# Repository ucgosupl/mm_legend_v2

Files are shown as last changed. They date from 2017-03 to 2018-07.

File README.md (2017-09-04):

# Legend v2 - the micromouse robot

master: 

dev: 

The purpose of micromouse robot is to find path in the labirynth. To accomplish this task, robot should control its motors, detect walls using distance sensors and run pathfinding alhorithms.

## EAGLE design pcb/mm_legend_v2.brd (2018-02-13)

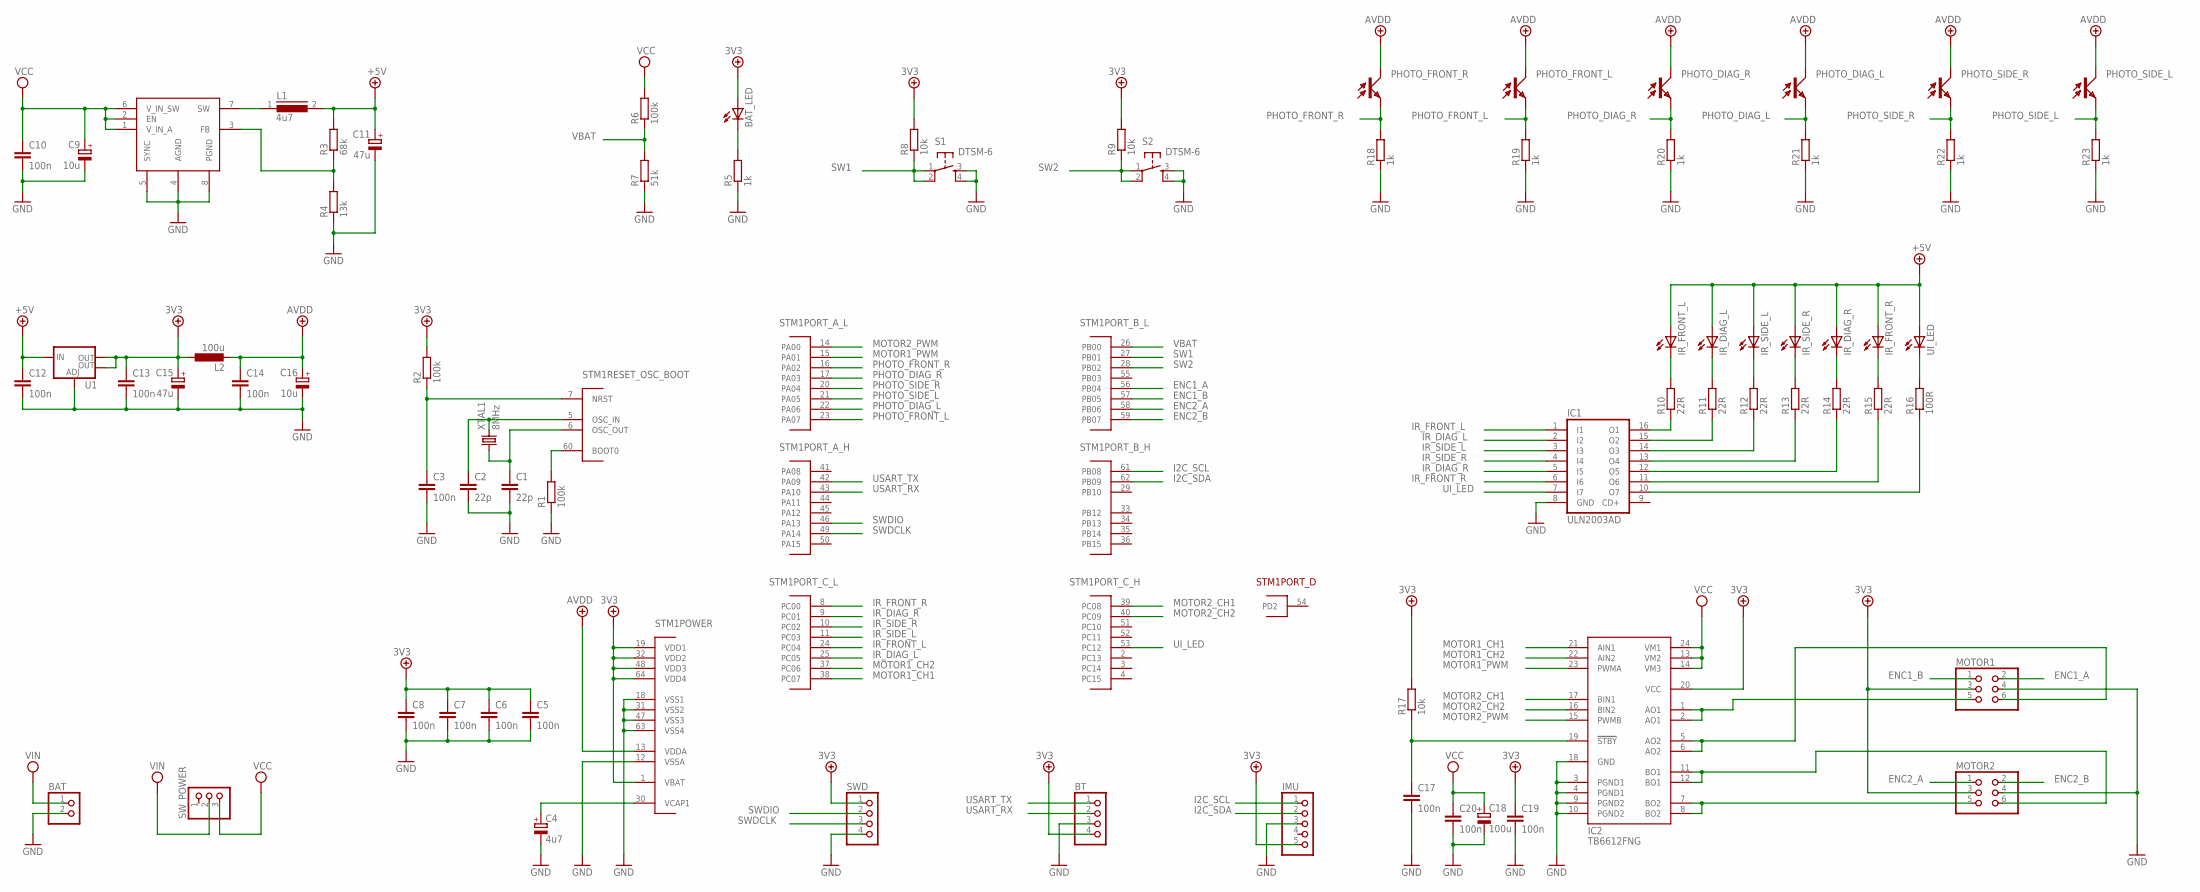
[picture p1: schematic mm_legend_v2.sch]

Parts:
BAT: PINHD-1X2; 1X02
BAT_LED: LEDCHIP-LED0805; CHIP-LED0805
BT: PINHD-1X4; 1X04
C1, C2: 22p; C0805K
C3, C5, C6, C7, C8, C10, C12, C13, C14, C17, C19, C20: 100n; C0805K
C4: 4u7; A/3216-18R
C9, C16: 10u; A/3216-18R
C11, C15: 47u; B/3528-21W
C18: 100u; C/6032-28R
IC1: ULN2003AD; SO16
IC2: TB6612FNG; SSOP24
IMU: PINHD-1X5; 1X05
IR_DIAG_L: LED5MM
IR_DIAG_R: LED5MM
IR_FRONT_L: LED5MM
IR_FRONT_R: LED5MM
IR_SIDE_L: LED5MM
IR_SIDE_R: LED5MM
L1: 4u7; DR74
L2: 100u; L1812
MOTOR1, MOTOR2: PINHD-2X3; 2X03
PHOTO_DIAG_L: PHOTO_TRANSISTOR_5MM; 5MM
PHOTO_DIAG_R: PHOTO_TRANSISTOR_5MM; 5MM
PHOTO_FRONT_L: PHOTO_TRANSISTOR_5MM; 5MM
PHOTO_FRONT_R: PHOTO_TRANSISTOR_5MM; 5MM
PHOTO_SIDE_L: PHOTO_TRANSISTOR_5MM; 5MM
PHOTO_SIDE_R: PHOTO_TRANSISTOR_5MM; 5MM
R1, R2, R6: 100k; R0805W
R3: 68k; R0805W
R4: 13k; R0805W
R5, R18, R19, R20, R21, R22, R23: 1k; R0805W
R7: 51k; R0805W
R8, R9, R17: 10k; R0805W
R10, R11, R12, R13, R14, R15: 22R; R0805W
R16: 100R; R0805W
S1, S2: DTSM-6
STM1: STM32F401RB; LQFP64
SWD: PINHD-1X4; 1X04
SW_POWER: PINHD-1X3; 1X03
U1: V_REG_LM1117SOT223; SOT223
U$2: ST1S10PHR; SO8
UI_LED: LEDCHIP-LED0805; CHIP-LED0805
XTAL1: 8MHz; SMD_50X32

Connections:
3V3: BAT_LED.A, BT.4, C5.1, C6.1, C7.1, C8.1, C13.1, C15.+, C19.1, IC2.20 (VCC), IMU.5, L2.1, MOTOR1.3, MOTOR2.3, R2.2, R8.2, R9.2, R17.2, STM1.1 (VBAT), STM1.19 (VDD1), STM1.32 (VDD2), STM1.48 (VDD3), STM1.64 (VDD4), SWD.1, U1.2 (OUT), U1.4 (OUT)
+5V: C11.+, C12.1, IR_DIAG_L.A, IR_DIAG_R.A, IR_FRONT_L.A, IR_FRONT_R.A, IR_SIDE_L.A, IR_SIDE_R.A, L1.2, R3.2, U1.3 (IN), UI_LED.A
AVDD: C14.1, C16.+, L2.2, PHOTO_DIAG_L.C, PHOTO_DIAG_R.C, PHOTO_FRONT_L.C, PHOTO_FRONT_R.C, PHOTO_SIDE_L.C, PHOTO_SIDE_R.C, STM1.13 (VDDA)
ENC1_A: MOTOR1.2, STM1.56 (PB04)
ENC1_B: MOTOR1.1, STM1.57 (PB05)
ENC2_A: MOTOR2.1, STM1.58 (PB06)
ENC2_B: MOTOR2.2, STM1.59 (PB07)
GND: BAT.2, BT.3, C1.2, C2.2, C3.2, C4.-, C5.2, C6.2, C7.2, C8.2, C9.-, C10.2, C11.-, C12.2, C13.2, C14.2, C15.-, C16.-, C17.2, C18.-, C19.2, C20.2, IC1.8 (GND), IC2.3 (PGND1), IC2.4 (PGND1), IC2.9 (PGND2), IC2.10 (PGND2), IC2.18 (GND), IMU.3, MOTOR1.4, MOTOR2.4, R1.1, R4.1, R5.1, R7.1, R18.1, R19.1, R20.1, R21.1, R22.1, R23.1, S1.3, S1.4, S2.3, S2.4, STM1.12 (VSSA), STM1.18 (VSS1), STM1.31 (VSS2), STM1.47 (VSS3), STM1.63 (VSS4), SWD.4, U1.1 (ADJ), U$2.4 (AGND), U$2.5 (SYNC), U$2.8 (PGND)
I2C_SCL: IMU.1, STM1.61 (PB08)
I2C_SDA: IMU.2, STM1.62 (PB09)
IR_DIAG_L: IC1.2 (I2), STM1.25 (PC05)
IR_DIAG_R: IC1.5 (I5), STM1.9 (PC01)
IR_FRONT_L: IC1.1 (I1), STM1.24 (PC04)
IR_FRONT_R: IC1.6 (I6), STM1.8 (PC00)
IR_SIDE_L: IC1.3 (I3), STM1.11 (PC03)
IR_SIDE_R: IC1.4 (I4), STM1.10 (PC02)
MOTOR1_CH1: IC2.21 (AIN1), STM1.38 (PC07)
MOTOR1_CH2: IC2.22 (AIN2), STM1.37 (PC06)
MOTOR1_PWM: IC2.23 (PWMA), STM1.15 (PA01)
MOTOR2_CH1: IC2.17 (BIN1), STM1.39 (PC08)
MOTOR2_CH2: IC2.16 (BIN2), STM1.40 (PC09)
MOTOR2_PWM: IC2.15 (PWMB), STM1.14 (PA00)
unnamed: R1.2, STM1.60 (BOOT0)
unnamed: C3.1, R2.1, STM1.7 (NRST)
unnamed: C1.1, STM1.6 (OSC_OUT), XTAL1.1
unnamed: C2.1, STM1.5 (OSC_IN), XTAL1.2
unnamed: BAT_LED.C, R5.2
unnamed: C17.1, IC2.19 (!STBY), R17.1
unnamed: R16.2, UI_LED.C
unnamed: IR_FRONT_L.K (C), R10.2
unnamed: C4.+, STM1.30 (VCAP1)
unnamed: IR_DIAG_L.K (C), R11.2
unnamed: IR_SIDE_L.K (C), R12.2
unnamed: IR_SIDE_R.K (C), R13.2
unnamed: IR_DIAG_R.K (C), R14.2
unnamed: IR_FRONT_R.K (C), R15.2
unnamed: IC1.16 (O1), R10.1
unnamed: IC1.15 (O2), R11.1
unnamed: IC1.14 (O3), R12.1
unnamed: IC1.13 (O4), R13.1
unnamed: IC1.12 (O5), R14.1
unnamed: IC1.11 (O6), R15.1
unnamed: IC1.10 (O7), R16.1
unnamed: L1.1, U$2.7 (SW)
unnamed: IC2.1 (AO1), IC2.2 (AO1), MOTOR1.5
unnamed: IC2.5 (AO2), IC2.6 (AO2), MOTOR1.6
unnamed: R3.1, R4.2, U$2.3 (FB)
unnamed: IC2.11 (BO1), IC2.12 (BO1), MOTOR2.6
unnamed: IC2.7 (BO2), IC2.8 (BO2), MOTOR2.5
PHOTO_DIAG_L: PHOTO_DIAG_L.E, R21.2, STM1.22 (PA06)
PHOTO_DIAG_R: PHOTO_DIAG_R.E, R20.2, STM1.17 (PA03)
PHOTO_FRONT_L: PHOTO_FRONT_L.E, R19.2, STM1.23 (PA07)
PHOTO_FRONT_R: PHOTO_FRONT_R.E, R18.2, STM1.16 (PA02)
PHOTO_SIDE_L: PHOTO_SIDE_L.E, R23.2, STM1.21 (PA05)
PHOTO_SIDE_R: PHOTO_SIDE_R.E, R22.2, STM1.20 (PA04)
SW1: R8.1, S1.1, S1.2, STM1.27 (PB01)
SW2: R9.1, S2.1, S2.2, STM1.28 (PB02)
SWDCLK: STM1.49 (PA14), SWD.3
SWDIO: STM1.46 (PA13), SWD.2
UI_LED: IC1.7 (I7), STM1.53 (PC12)
USART_RX: BT.2, STM1.43 (PA10)
USART_TX: BT.1, STM1.42 (PA09)
VBAT: R6.1, R7.2, STM1.26 (PB00)
VCC: C9.+, C10.1, C18.+, C20.1, IC2.13 (VM2), IC2.14 (VM3), IC2.24 (VM1), R6.2, SW_POWER.3, U$2.1 (V_IN_A), U$2.2 (EN), U$2.6 (V_IN_SW)
VEE: BAT.1, SW_POWER.2

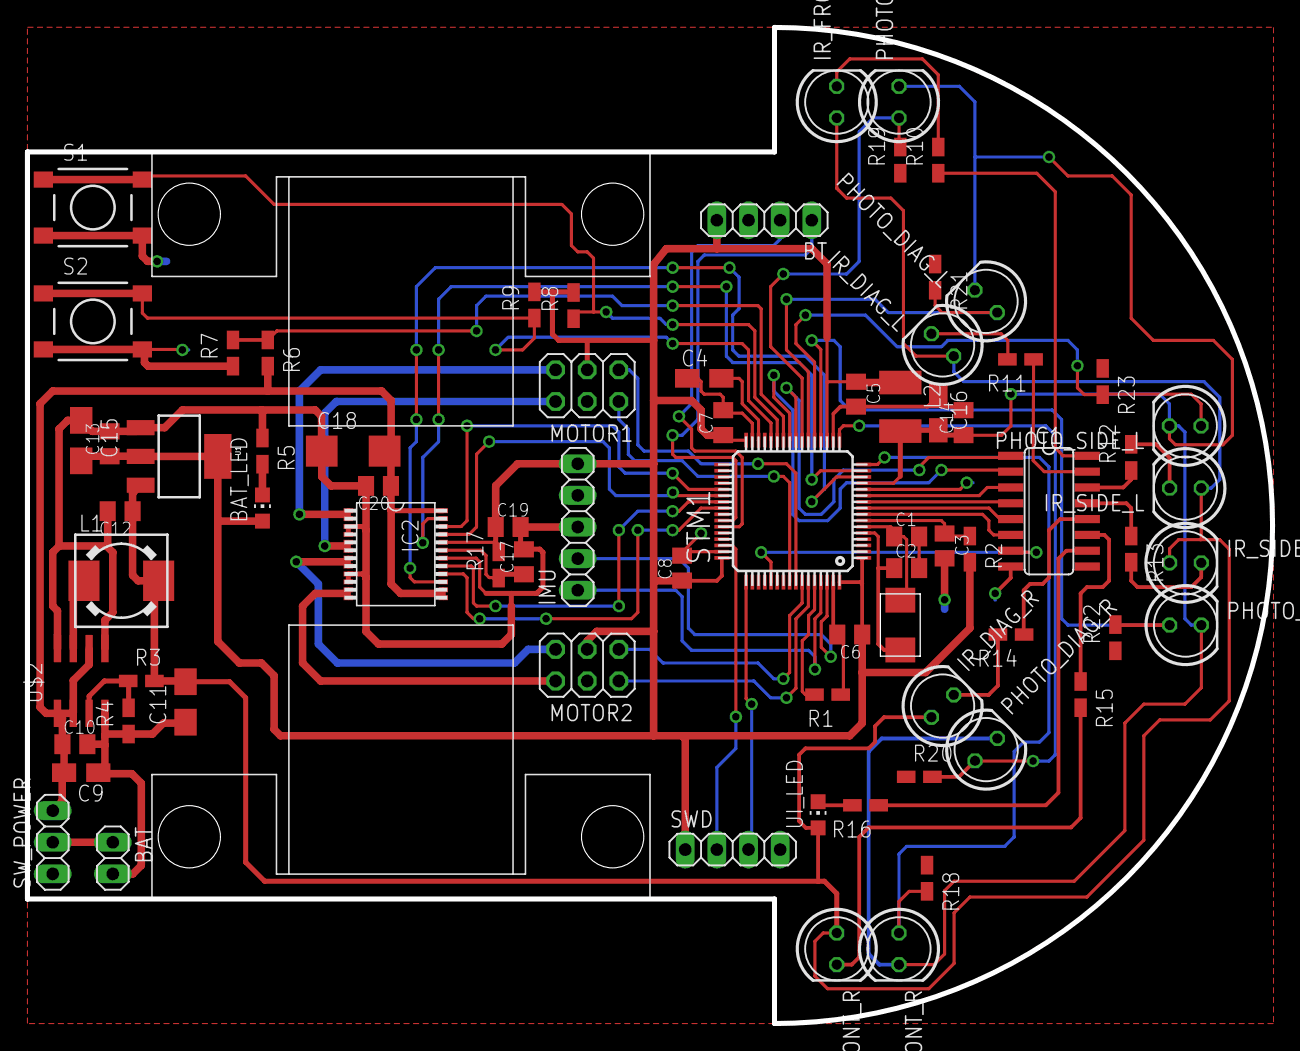
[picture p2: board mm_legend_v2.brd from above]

Board: 2 copper layers, 100.0 x 80.0 mm, 76 parts (0 on the bottom side), 65 nets.

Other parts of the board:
U$1, U$3: MOTOR_HOLDER

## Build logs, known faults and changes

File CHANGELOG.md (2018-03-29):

Changelog
============
All notable changes to this project will be documented in this file.

The format is based on [Keep a Changelog](http://keepachangelog.com/en/1.0.0/)
and this project adheres to [Semantic Versioning](http://semver.org/spec/v2.0.0.html).

## [Unreleased]
------------------------

### Added

### Changed

### Fixed

### Deprecated

### Removed

## [0.5.0] - 2018-03-30
------------------------

### Added
- map_update: present/absent wall detection.
- map_validate: present/absent walls are added only after their detection count reaches threshold.
- wall_detection: wall sensor position calculation based on offset from robot position.
- wall_detection: wall detection position calculation based on sensor position and measured distance.

### Changed
- map: change wall orientation so x and y indices grow with coordinates.
- mazetool: update print functions to show maze in proper orientation.
- wall_sensor: change module name from wall to wall_sensor.

### Fixed

### Deprecated

### Removed

## [0.5.0] - 2018-03-24
------------------------

### Added
- adc: add adc implementation.
- led: add led driver implementation.
- map: add module storing labirynth map.
- pcb: new PCB design.
- project: add incremental compilation to makefiles.
- scripts: add scripts for generating sensor lookup table from measurements.
- solver: add implementation of maze solver.
- vbat: add battery saving procedure.
- wall: add wall sensor task.
- wall: add conversion routine separate for every sensor.

### Changed
- pcb: move status led to the front.

### Fixed
- pcb: change wall sensor placement - Fixes issue #7.
- pcb: reroute paths to h-bridge around imu sensor - Fixes issue #6.
- pcb: fix motor connector wiring - Fixes issue #1.

### Deprecated

### Removed

## [0.4.0] - 2017-12-23
------------------------

### Added
- external: add matrix calculations library.
- position: implement position estimation based on EKF.
- position: implement gyro drift reduction.

### Changed

### Fixed
- imu: add timeout in startup procedure to eliminate junk readings.

### Deprecated

### Removed

## [0.3.0] - 2017-11-18
------------------------

### Added
- encoder: implement encoders driver.
- i2c: add i2c master driver.
- imu: add IMU task reading data from sensor.
- logger: implement logger task and integrate it with system printf.
- motor: implement PID controller for forward velocity.
- motor: implement PID controller for angular velocity.
- pcb: fix motor connectors and BT connector.
- uart: implement Tx functionality.

### Changed

### Fixed
- ci: Travis failing after gcc update - use fixed gcc version and precompiled binary.

### Deprecated

### Removed

## [0.2.0] - 2017-07-02
------------------------

### Added
- console: added ability to control motors manually using console.
- console: implement uart console task.
- hbridge: TB6612 H-Bridge driver implementation.
- src: added skeleton interfaces for code components.
- uart: implement Rx functionality.

### Changed

### Fixed
- src: fixed wrong bus frequency definitions.

### Deprecated

### Removed

## [0.1.1] - 2017-04-22
------------------------

### Added

### Changed

### Fixed
- ci: remove Travis-CI dependency on fixed gcc version.

### Deprecated

### Removed

## 0.1.0 - 2017-04-22
------------------------

### Added
- ci: initial Travis-CI configuration.
- pcb: designed electric circuit.
- pcb: designed PCB.
- src: initial project setup.
- unit_test: configured CppUTest.

### Changed

### Fixed

### Deprecated

### Removed

[Unreleased]: https://github.com/ucgosupl/mm_legend_v2/compare/v0.5.0...dev
[0.1.1]: https://github.com/ucgosupl/mm_legend_v2/compare/v0.1.0...v0.1.1
[0.2.0]: https://github.com/ucgosupl/mm_legend_v2/compare/v0.1.1...0.2.0
[0.3.0]: https://github.com/ucgosupl/mm_legend_v2/compare/0.2.0...v0.3.0
[0.4.0]: https://github.com/ucgosupl/mm_legend_v2/compare/0.3.0...v0.4.0
[0.5.0]: https://github.com/ucgosupl/mm_legend_v2/compare/0.4.0...v0.5.0
[0.6.0]: https://github.com/ucgosupl/mm_legend_v2/compare/0.5.0...v0.6.0

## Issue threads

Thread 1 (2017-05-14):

PCB error - wrong pinout on motor connectors

ucgosupl, 2017-05-14:
According to documentation, Faulhaber 1717T006IE16 connector have following pinout:
6 4 2
5 3 1

where:
1 - motor -
2 - motor +
3 - GND
4 - VCC
5 - Encoder B
6 - Encoder A

On the board connector is:
5 3 1
6 4 2
Pins 5-6 and 1-2 can be inverted but inverting 3-4 causes providing negative voltage to the board.

ucgosupl, 2017-10-22:
Left motor connector still with wrong pinout

Closed 2018-02-14.

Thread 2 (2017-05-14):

Design and 3D print gear mounted to motor shaft using screw

ucgosupl, 2017-05-14:
Principle of operation like in: https://www.ctmeca.com/vitnw/technicalFilesCtmeca.php?item=F first method.
Need to check if it is possible to 3D print gear to be used with M1.6 screw.

ucgosupl, 2017-09-24:
Screws are glued and it works fine.

Closed 2017-09-24.

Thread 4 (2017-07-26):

Motor identifiaction

ucgosupl, 2017-07-26:
Gather motor-encoder characteristics for various motor power settings.

ucgosupl, 2017-07-26:
Gathered data in commit: 9c18ef3
Now need to determine transfer function based on these data. There will be separate TF for left and right motor as they behave diffferently due to inaccuracy of mechanical parts.

ucgosupl, 2017-08-08:
Gathered transfer functions.
For left motor: 1.682 / (0.2742 s + 1)
For right motor: 1.59 / (0.2222 s + 1)

PID settings for these models:
P = 2.61, I = 11.58, D = 0

The same PID will be used for both motors

ucgosupl, 2017-09-04:
Made adjustments to model. New model is:
1.4 / (0.215 s + 1)

New PID values for linear velocity are:
P = 6.6869
I  = 0.0
D = 0.03639

ucgosupl, 2017-09-24:
Tuned pid for linear velocity, but glued wheels have other characteristics so all process should be repeated.

Closed 2017-09-24.

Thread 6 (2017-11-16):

PCB - motor direction paths

ucgosupl, 2017-11-16:
Signals Motor 1/2 CH1/2 should be routed around imu connector, not between bads. Thin routes are easy to damage.

Closed 2018-02-14.

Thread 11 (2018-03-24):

[unit_test] Change unit test framework to Unity + mocklib

ucgosupl, 2018-03-24:
CppUTest mocking features are not enough for my use and are hard to configure.
Eclipse doesn't support cpp that well or I have problems with proper configuration.
Using mocklib will be opportunity to improve my mocklib project.

ucgosupl, 2018-04-08:
Decided to give CppUTest one more try. Won't fix for now.

Closed 2018-04-08.

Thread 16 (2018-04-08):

[search] add info about robot orientation to state machine

ucgosupl, 2018-04-08:
State machine needs info about current robot orientation to be able to choose correct next move.

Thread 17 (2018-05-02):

Add emergency stop when too close to wall

ucgosupl, 2018-05-02:
To avoid collision, navigation algorithm should be replaced by emergency stop to protect robot from damage. Along with stopping all motors, console message and led signal should be added so this state is easly recognized.

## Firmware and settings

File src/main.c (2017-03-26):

/*
 * File: main.c
 * Author: GAndaLF
 * Brief: Main file for main_program target.
 */

#include "platform_specific.h"

#include "FreeRTOSConfig.h"
#include "FreeRTOS.h"
#include "task.h"
#include "queue.h"
#include "timers.h"
#include "semphr.h"

#include "core_init/core_init.h"
#include "diag/diag.h"

void main(void)
{
    core_init();

    /* Place your initialisation code here. */
    diag_task_init();
    vTaskStartScheduler();

    while (1)
        ;
}

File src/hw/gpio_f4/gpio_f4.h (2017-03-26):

/*
 * File:    gpio_f4.h
 * Author:  GAndaLF
 * Brief:   GPIO configuration functions.
 */

#ifndef _GPIO_F4_H_
#define _GPIO_F4_H_

#ifdef __cplusplus
 extern "C" {
#endif /* __cplusplus */

/**
 * @defgroup hw_gpio
 * @{
 */

/** GPIO mode of operation - input. */
#define GPIO_MODE_INPUT       0
/** GPIO mode of operation - output. */
#define GPIO_MODE_OUTPUT      1
/** GPIO mode of operation - alternative function. */
#define GPIO_MODE_AF          2
/** GPIO mode of operation - analog input. */
#define GPIO_MODE_ANALOG      3

/** GPIO state change speed - low. */
#define GPIO_SPEED_LOW        0
/** GPIO state change speed - medium. */
#define GPIO_SPEED_MEDIUM     1
/** GPIO state change speed - fast. */
#define GPIO_SPEED_FAST       2
/** GPIO state change speed - high. */
#define GPIO_SPEED_HIGH       3

/** GPIO input pull up/down setting - none. */
#define GPIO_PUPD_NONE        0
/** GPIO input pull up/down setting - pull up. */
#define GPIO_PUPD_PU          1
/** GPIO input pull up/down setting - pull down. */
#define GPIO_PUPD_PD          2

/** GPIO alternative function - JTAG. */
#define GPIO_AF_JTAG          0
/** GPIO alternative function - Microcontroller Clock Output. */
#define GPIO_AF_MCO           0
/** GPIO alternative function - RTC. */
#define GPIO_AF_RTC           0
/** GPIO alternative function - TRACE. */
#define GPIO_AF_TRACE         0
/** GPIO alternative function - Timer 1. */
#define GPIO_AF_TIM1          1
/** GPIO alternative function - Timer 2. */
#define GPIO_AF_TIM2          1
/** GPIO alternative function - Timer 3. */
#define GPIO_AF_TIM3          2
/** GPIO alternative function - Timer 4. */
#define GPIO_AF_TIM4          2
/** GPIO alternative function - Timer 5. */
#define GPIO_AF_TIM5          2
/** GPIO alternative function - Timer 8. */
#define GPIO_AF_TIM8          3
/** GPIO alternative function - Timer 9. */
#define GPIO_AF_TIM9          3
/** GPIO alternative function - Timer 10. */
#define GPIO_AF_TIM10         3
/** GPIO alternative function - Timer 11. */
#define GPIO_AF_TIM11         3
/** GPIO alternative function - I2C 1. */
#define GPIO_AF_I2C1          4
/** GPIO alternative function - I2C 2. */
#define GPIO_AF_I2C2          4
/** GPIO alternative function - I2C 3. */
#define GPIO_AF_I2C3          4
/** GPIO alternative function - SPI 1. */
#define GPIO_AF_SPI1          5
/** GPIO alternative function - SPI 2. */
#define GPIO_AF_SPI2          5
/** GPIO alternative function - I2S 2. */
#define GPIO_AF_I2S2          5
/** GPIO alternative function - I2S 2 EXT. */
#define GPIO_AF_I2S2EXT       5
/** GPIO alternative function - SPI 3. */
#define GPIO_AF_SPI3          6
/** GPIO alternative function - I2S EXT. */
#define GPIO_AF_I2SEXT        6
/** GPIO alternative function - I2S 3. */
#define GPIO_AF_I2S3          6
/** GPIO alternative function - USART 1. */
#define GPIO_AF_USART1        7
/** GPIO alternative function - USART 2. */
#define GPIO_AF_USART2        7
/** GPIO alternative function - USART 3. */
#define GPIO_AF_USART3        7
/** GPIO alternative function - I2S 3 EXT. */
#define GPIO_AF_I2S3EXT       7
/** GPIO alternative function - UART 4. */
#define GPIO_AF_UART4         8
/** GPIO alternative function - UART 5. */
#define GPIO_AF_UART5         8
/** GPIO alternative function - USART6. */
#define GPIO_AF_USART6        8
/** GPIO alternative function - CAN 1. */
#define GPIO_AF_CAN1          9
/** GPIO alternative function - CAN 2. */
#define GPIO_AF_CAN2          9
/** GPIO alternative function - Timer 12. */
#define GPIO_AF_TIM12         9
/** GPIO alternative function - Timer 13. */
#define GPIO_AF_TIM13         9
/** GPIO alternative function - Timer 14. */
#define GPIO_AF_TIM14         9
/** GPIO alternative function - USB On-The-Go Full Speed 1. */
#define GPIO_AF_OTGFS1        10
/** GPIO alternative function - USB On-The-Go High Speed. */
#define GPIO_AF_OTGHS         10
/** GPIO alternative function - Ethernet. */
#define GPIO_AF_ETH           11
/** GPIO alternative function - FSMC. */
#define GPIO_AF_FSMC          12
/** GPIO alternative function - SDIO. */
#define GPIO_AF_SDIO          12
/** GPIO alternative function - USB On-The-Go Full Speed 2. */
#define GPIO_AF_OTGFS2        12
/** GPIO alternative function - DCMI. */
#define GPIO_AF_DCMI          13
/** GPIO alternative function - Alternative function 14. */
#define GPIO_AF_AF14          14
/** GPIO alternative function - Eventout. */
#define GPIO_AF_EVENTOUT      15

/**
 * @brief Function sets GPIO pin mode.
 *
 * @param gpio                         Port to set.
 * @param pin                          Pin to set.
 * @param conf                         Mode to set.
 */
void gpio_mode_config(GPIO_TypeDef * gpio, int32_t pin, int32_t conf);

/**
 * @brief Function sets GPIO pin in push-pull mode.
 *
 * @param gpio                         Port to set.
 * @param pin                          Pin to set.
 */
#define gpio_otype_pp_set(gpio, pin)   gpio->OTYPER &= ~(1<<pin);
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

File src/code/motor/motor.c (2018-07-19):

/*
 * file:	motor.c
 * author:	GAndaLF
 * brief:   Motor control task.
 */

#include "platform_specific.h"
#include <string.h>
#include <stdlib.h>
#include <math.h>

#include "encoder/encoder.h"
#include "hbridge/hbridge.h"
#include "pid/pid.h"

#include "motor.h"

/** Maximum allowed motor power. */
#define MOTOR_POWER_MAX     1000

/** Minimum allowed motor power. */
#define MOTOR_POWER_MIN     0

/** Number of cogs in motor gear. */
#define GEAR_MOTOR              10.0f
/** Number of cogs in wheel gear. */
#define GEAR_WHEEL              40.0f
/** Number of encoder ticks per full motor cycle - 16 ticks per cycle, rising and falling edge, A and B. */
#define TICKS_PER_MOTOR_CYCLE   64.0f
/** Circumference of the wheel. */
#define WHEEL_CIRC_MM           69.0f

/** Convert encoder ticks to mm. */
#define TICKS_TO_MM(ticks)      \
    (((ticks) * GEAR_MOTOR * WHEEL_CIRC_MM) / (GEAR_WHEEL * TICKS_PER_MOTOR_CYCLE))

/** Convert mm to encoder ticks. */
#define MM_TO_TICKS(mm)         \
    (((mm) * GEAR_WHEEL * TICKS_PER_MOTOR_CYCLE) / (GEAR_MOTOR * WHEEL_CIRC_MM))

#define SAMPLING_TIME_S 0.010f

/** Forward velocity controller PID proportional gain. */
#define FORWARD_PID_P   2.0f
/** Forward velocity controller PID integral gain. */
#define FORWARD_PID_I   (1.0f * SAMPLING_TIME_S)
/** Forward velocity controller PID derivative gain. */
#define FORWARD_PID_D   (0.0f / SAMPLING_TIME_S)

/** Angular velocity controller PID proportional gain. */
#define ANGULAR_PID_P   1.0f
/** Angular velocity controller PID integral gain. */
#define ANGULAR_PID_I   (1.0f * SAMPLING_TIME_S)
/** Angular velocity controller PID derivative gain. */
#define ANGULAR_PID_D   (0.0f / SAMPLING_TIME_S)

#define MOTOR_ANGULAR_OFFSET    0

#define ROBOT_WIDTH_MM  80.0f

struct motor_params
{
    float vlinear;
    float vangular;

    int32_t vleft_read;
    int32_t vright_read;
};

static struct motor_params motor_params;
static struct pid_params forward_pid;
static struct pid_params angular_pid;

static void motor_task(void *params);
static int32_t motor_power_limits(float u);

void motor_task_init(void)
{
    memset(&motor_params, 0, sizeof(struct motor_params));

    pid_init(&forward_pid, FORWARD_PID_P, FORWARD_PID_I, FORWARD_PID_D);
    pid_init(&angular_pid, ANGULAR_PID_P, ANGULAR_PID_I, ANGULAR_PID_D);

    encoder_init();
    hbridge_init();

    rtos_task_create(motor_task, "motor", MOTOR_STACKSIZE, MOTOR_PRIORITY);
}

float motor_vleft_get(void)
{
    return TICKS_TO_MM(motor_params.vleft_read);
}

float motor_vright_get(void)
{
    return TICKS_TO_MM(motor_params.vright_read);
}

void motor_vlinear_set(float val)
{
    motor_params.vlinear = MM_TO_TICKS(2.0f * val * SAMPLING_TIME_S);
}

void motor_vangular_set(float val)
{
    motor_params.vangular = MM_TO_TICKS(val * 2.0f * M_PI *
            ROBOT_WIDTH_MM * SAMPLING_TIME_S / 360.0f);
}

void motor_all_off(void)
{
    hbridge_left_speed_set(0);
    hbridge_right_speed_set(0);
}

void motor_pid_linear_reset(void)
{
    pid_reset(&forward_pid);
}

void motor_pid_angular_reset(void)
{
    pid_reset(&angular_pid);
}

static void motor_task(void *params)
{
    (void) params;

    float forward;
    float angle;
    float u_forward = 0;
    float u_angular = 0;
    float u_left = 0;
    float u_right = 0;
    tick_t last;

    while (1)
    {
        last = rtos_tick_count_get();

        motor_params.vleft_read = encoder_left_read();
        motor_params.vright_read = encoder_right_read();

        forward = motor_params.vright_read + motor_params.vleft_read;
        angle = motor_params.vright_read - motor_params.vleft_read;

        /* Forward controller */
        u_forward = pid_iter(&forward_pid, motor_params.vlinear, forward);

        /* Angular controller */
        u_angular = pid_iter(&angular_pid, motor_params.vangular, angle);

        /* Fusion of two controllers */
        u_left = u_forward - u_angular + MOTOR_ANGULAR_OFFSET;
        u_right = u_forward + u_angular - MOTOR_ANGULAR_OFFSET;

        /* Limits */
        u_left = motor_power_limits(u_left);
        u_right = motor_power_limits(u_right);

        hbridge_left_speed_set(u_left);
        hbridge_right_speed_set(u_right);

        rtos_delay_until(&last, 10);
    }
}

static int32_t motor_power_limits(float u)
{
    int32_t retval;
    int32_t u_int;

    u_int = (int32_t)u;

    /* Maximum motor power value conditions - bigger values are not handled. */
    if (MOTOR_POWER_MAX < u_int)
    {
        retval = MOTOR_POWER_MAX;
    }
    else if (-MOTOR_POWER_MAX > u_int)
    {
        retval = -MOTOR_POWER_MAX;
    }
    /* Minimum nonzero value condition - lower values might damage motor. */
    else if (MOTOR_POWER_MIN > abs(u_int))
    {
        retval = 0;
    }
    else
    {
        /* Input value correct, don't need to do anything. */
        retval = u_int;
    }

    return retval;
}

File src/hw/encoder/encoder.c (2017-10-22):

/*
 * file:	encoder.c
 * author:	GAndaLF
 * brief:   Motor encoders driver.
 */

#include "platform_specific.h"

#include "gpio_f4/gpio_f4.h"

#include "encoder.h"

/** Encoder 1 channel A pin number - PB04 */
#define ENC_1A_PIN                  4
/** Encoder 1 channel B pin number - PB05 */
#define ENC_1B_PIN                  5
/** Encoder 2 channel A pin number - PB06 */
#define ENC_2A_PIN                  6
/** Encoder 2 channel B pin number - PB07 */
#define ENC_2B_PIN                  7

/**
 * Encoder mode 1 setting in SMS field of TIM->SMCR register.
 *
 * Count up-down only on channel A edge.
 */
#define TIM_SMS_MODE_ENC1           1
/**
 * Encoder mode 2 setting in SMS field of TIM->SMCR register.
 *
 * Count up-down only on channel B edge.
 */
#define TIM_SMS_MODE_ENC2           2
/**
 * Encoder mode 3 setting in SMS field of TIM->SMCR register.
 *
 * Count up-down on edge on either A or B channel.
 */
#define TIM_SMS_MODE_ENC3           3

/** Set Capture/Compare channel to output mode. */
#define TIM_CCxS_MODE_OUT           0
/** Set Capture/Compare channel to input mode mapped on TI1. */
#define TIM_CCxS_MODE_IN_T1         1
/** Set Capture/Compare channel to input mode mapped on TI2. */
#define TIM_CCxS_MODE_IN_T2         2
/** Set Capture/Compare channel to input mode mapped on TRC. */
#define TIM_CCxS_MODE_IN_TRC        3

/** Bit offset of SMS field in SMCR register. */
#define TIM_SMCR_SMS_BIT            0

/** Bit offset of CC1S field in CCMR1 register. */
#define TIM_CCMR1_CC1S_BIT          0
/** Bit offset of CC2S field in CCMR1 register. */
#define TIM_CCMR1_CC2S_BIT          8

/**
 * Initialize GPIOs for encoder inputs.
 */
static void gpio_init(void);

/**
 * Initialize timers for encoder inputs.
 */
static void timer_init(void);

void encoder_init(void)
{
    gpio_init();
    timer_init();
}

int32_t encoder_left_read(void)
{
    int16_t val;

    val = -TIM3->CNT;
    TIM3->CNT = 0;

    return (int32_t) val;
}

int32_t encoder_right_read(void)
{
    int16_t val;

    val = -TIM4->CNT;
    TIM4->CNT = 0;

    return (int32_t) val;
}

static void gpio_init(void)
{
    RCC->AHB1ENR |= RCC_AHB1ENR_GPIOBEN;

    gpio_mode_config(GPIOB, ENC_1A_PIN, GPIO_MODE_AF);
    gpio_mode_config(GPIOB, ENC_1B_PIN, GPIO_MODE_AF);
    gpio_mode_config(GPIOB, ENC_2A_PIN, GPIO_MODE_AF);
    gpio_mode_config(GPIOB, ENC_2B_PIN, GPIO_MODE_AF);

    gpio_af_config(GPIOB, ENC_1A_PIN, GPIO_AF_TIM3);
    gpio_af_config(GPIOB, ENC_1B_PIN, GPIO_AF_TIM3);
    gpio_af_config(GPIOB, ENC_2A_PIN, GPIO_AF_TIM4);
    gpio_af_config(GPIOB, ENC_2B_PIN, GPIO_AF_TIM4);
}

static void timer_init(void)
{
    RCC->APB1ENR |= RCC_APB1ENR_TIM3EN | RCC_APB1ENR_TIM4EN;

    /* Select encoder mode */
    TIM3->SMCR = (TIM_SMS_MODE_ENC3 << TIM_SMCR_SMS_BIT);
    TIM4->SMCR = (TIM_SMS_MODE_ENC3 << TIM_SMCR_SMS_BIT);

    /* Set CCR1 as T1, CCR2 as T2 */
    TIM3->CCMR1 = (TIM_CCxS_MODE_IN_T1 << TIM_CCMR1_CC1S_BIT) |
            (TIM_CCxS_MODE_IN_T1 << TIM_CCMR1_CC1S_BIT);
    TIM4->CCMR1 = (TIM_CCxS_MODE_IN_T1 << TIM_CCMR1_CC1S_BIT) |
            (TIM_CCxS_MODE_IN_T1 << TIM_CCMR1_CC1S_BIT);

    /* Configure auto reload, so 0xFFFF is after 0 when downcounting */
    TIM3->ARR = 0xFFFF;
    TIM4->ARR = 0xFFFF;

    /* Enable timers */
    TIM3->CR1 = TIM_CR1_CEN;
    TIM4->CR1 = TIM_CR1_CEN;
}

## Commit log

2017-03-05 pcb: added circuit diagram.
    [mm_legend_v2.sch]
2017-03-13 pcb: added library parts used for circuit and pcb.
2017-03-13 pcb: created pcb design.
    [mm_legend_v2.brd, mm_legend_v2.sch]
2017-03-18 pcb: minor changes in pcb and schematic.
    [mm_legend_v2.brd, mm_legend_v2.sch]
2017-03-18 pcb: redesigned pcb.
    [mm_legend_v2.brd]
2017-03-26 project: added cpputest unit test framework.
2017-05-03 led: added prototypes for led driver functions.
2017-05-03 adc: added prototypes for ADC driver functions.
2017-05-03 photo: added prototypes for phototransistor module functions.
2017-05-03 vbat: added prototypes for battery monitor functions.
2017-05-03 wall: added prototypes for wall detection module functions.
2017-05-03 hbridge: added prototypes for H-bridge module functions.
2017-05-03 encoder: added prototypes for encoder driver functions.
2017-05-03 pid: added prototypes for PID controller functions.
2017-05-03 motor: added prototypes for motor control module functions.
2017-05-03 i2c: added prototypes for I2C master driver.
2017-05-03 imu: added prototypes for IMU sensors module functions.
2017-05-09 usart: added prototypes for USART driver functions.
2017-05-09 logger: added prototypes for logger module functions.
2017-05-09 console: added prototypes for debug console functions.
2017-05-13 button: added prototypes for button driver functions.
2017-05-13 user_interface: added prototypes for user interface functions.
2017-05-13 hbridge: implemented H-bridge driver and hardware test.
2017-07-02 usart: add implementation of usart Tx.
    USART Tx is implemented using DMA.
    HW test target - logger - is created.
2017-07-02 logger: add logger implementation and connect it with system printf.
2017-07-26 hw_test: added motor_ident hw_test target.
2017-07-26 button: add button driver implementation.
2017-07-26 encoder: add encoder implementation
2017-07-26 data: gather motor identification data - issue #3
2017-07-28 data: create script for motor identification - refers to #4
2017-08-08 data: create matlab scripts for processing motor ident data - refers to #4.
2017-09-04 pid: add pid controller implementation.
2017-09-04 motor: add motor task implementation.
2017-09-04 hw_test: add motor linear regulation test.
2017-09-04 hw_test: add imu test template.
2017-09-06 imu: add i2c driver and imu task.
2017-09-15 hw_test/motor_linear: fixed header comments.
2017-09-24 pcb: update pcb and schematic.
    Changes:
    - Moved BT connector away from motor holder.
    - Changed pinout of motor connectors - fix issue #1.
    - Added thicker lines for motor + and - signals.
    [mm_legend_v2.brd, mm_legend_v2.sch]
2017-10-22 pcb: updated vbat resistors to real values.
    Until now resistor values were 20k and 100k. 20k resistor doesn't exist in the series.
    [mm_legend_v2.brd, mm_legend_v2.sch]
2017-10-22 motor: update forward and backward functions for new motor orientation.
2017-10-22 encoder: adjust encoder measurements to return positive values when moving forward.
2017-10-22 motor: calculate new PID settings for linear movement.
2017-10-23 imu: add initial delay to imu task to allow sensor to power up.
2017-10-23 hw_test/motor_ident: adapt for angular velocity.
2017-10-29 imu: change gyro and accelerometer sampling frequency.
    High sample frequency caused higher exposure to noise generated by mechanical vibration caused by motors.
    [imu.c]
2017-11-18 hbridge: increase motor power resolution from 100 to 1000.
2017-11-18 motor: change function return values to float in api functions.
2017-11-18 data: gather data for angular velocity controller.
2017-11-18 scripts: create script and simulink model for angular velocity controller tuning.
2017-11-18 motor: implement angular velocity controller.
    Also added tools for angular controller tests in hw test target motor_linear.
2017-11-18 scripts: update simulink model for angular velocity controller.
2017-12-07 motor: update angular controller to use correct orientation angle.
    [motor.c]
2017-12-13 position: fix bugs with position estimation.
    - Ticks per motor cycle now accounts for encoder rising/falling edge on both channels A and B
    - Angular velocity from gyroscope is counted backwards compared to orientation angle
    - Angular velocity from encoders are measured in radians, conversion to degrees is necessary
    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
    [motor.c, position.c]
2017-12-20 imu: add hw test for imu sensor initial states after power up.
    After power up first few gyro samples are bogus. Added delay to remove this effect.
2017-12-21 position: add gyro bias estimation.
2017-12-22 position: modify initial gyro estimation
2018-01-21 led: add led driver implementation.
2018-01-21 wall: add led handling to wall task.
2018-01-22 hw_test: add wall sensor hw test.
2018-01-22 adc: add ADC implementation.
2018-02-04 vbat: fix bug with wrong ADC read values for vbat channel.
    The reason was not enabled GPIO port for VBAT. All other ADC channels were on GPIOA only vbat on GPIOB.
    [adc.c]
2018-02-04 vbat: update battery discharge threshold.
    Threshold set to 7V after analysing lipol discharge characteristics.
2018-02-05 wall: gather wall sensor measurements.
2018-02-05 wall: conversion between adc values and distance.
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2018-02-12 pcb: fix motor connector wiring.
    Fix issue #1.
    [mm_legend_v2.brd, mm_legend_v2.sch]
2018-02-12 pcb: reroute paths to h-bridge around imu sensor.
    Fixes issue #6.
    [mm_legend_v2.brd]
2018-02-12 pcb: move status led to the front.
    [mm_legend_v2.brd]
2018-02-13 pcb: change wall sensor placement.
    Fixes #7.
    [mm_legend_v2.brd]
2018-03-06 solver: prototype implementation of maze solver.
    Handling mazetool in unit tests to read mazes from the file and load to map.
2018-03-06 solver: fix failing mazetool test.
    Mazetool tests are used only as framework to run solver on existing maze files. These are not real tests.
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2018-03-21 scripts: add generate lookups script creating c array for every sensor.
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2018-03-22 wall: update naming of sensors in code and scripts.
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2018-03-29 wall_detection: add sensor position calculation.
    Sensor position is shifted from robot reference point by some offset. Position of every sensor is calculated so position of wall detected by them could be estimated more precisely. Closes #8.
2018-03-29 mazetool: fix printing laibrynth layouts.
2018-06-29 motor: update pid controller.
    Now PID regulator depends on last value of u(t).
    Updated tuning parameters - lower values are needed with new PID calculation.
    Removed dependency on imu from motor_linear hardware test.
2018-07-12 scripts: update scripts for identification of angular velocity.
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2018-07-12 motor: fix motor controller.
    - Single forward velocity controller instead left and right.
    - Angular velocity controller uses encoders instead of gyro.
    - Angular set val given in angle and calculated to ticks.
    - Tune angluar PID.
    - Temporarily remove motor control signal lower bound.
    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
    [motor.c]
2018-07-12 hw_test: update motor linear test.
    - Update set values for forward and angular velocity.
    - Rename encoder data to wheel data as this value is velocity in mm/Ts not ticks.
    - Print wheel data and control signal instead of gyro.
    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
2018-07-18 motor: fix converting velocity from mm and deg to ticks.
    [motor.c]
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2018-07-19 motor: fix motor control for forward velocity.
    [motor.c]
2018-07-19 pid: fix anti-windup bound.
2018-07-19 motor: fix formatting.
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2018-07-19 motor: add pid state resetting.
    Pid state could be reset when not moving to remove effect of integral term error cumulating when control is off.
    [motor.c]

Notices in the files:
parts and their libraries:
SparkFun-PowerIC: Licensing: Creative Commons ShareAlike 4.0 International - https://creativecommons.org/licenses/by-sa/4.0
